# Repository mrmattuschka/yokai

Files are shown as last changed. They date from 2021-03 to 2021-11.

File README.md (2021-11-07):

# YŌKAI - An e-Paper navigation display for Komoot

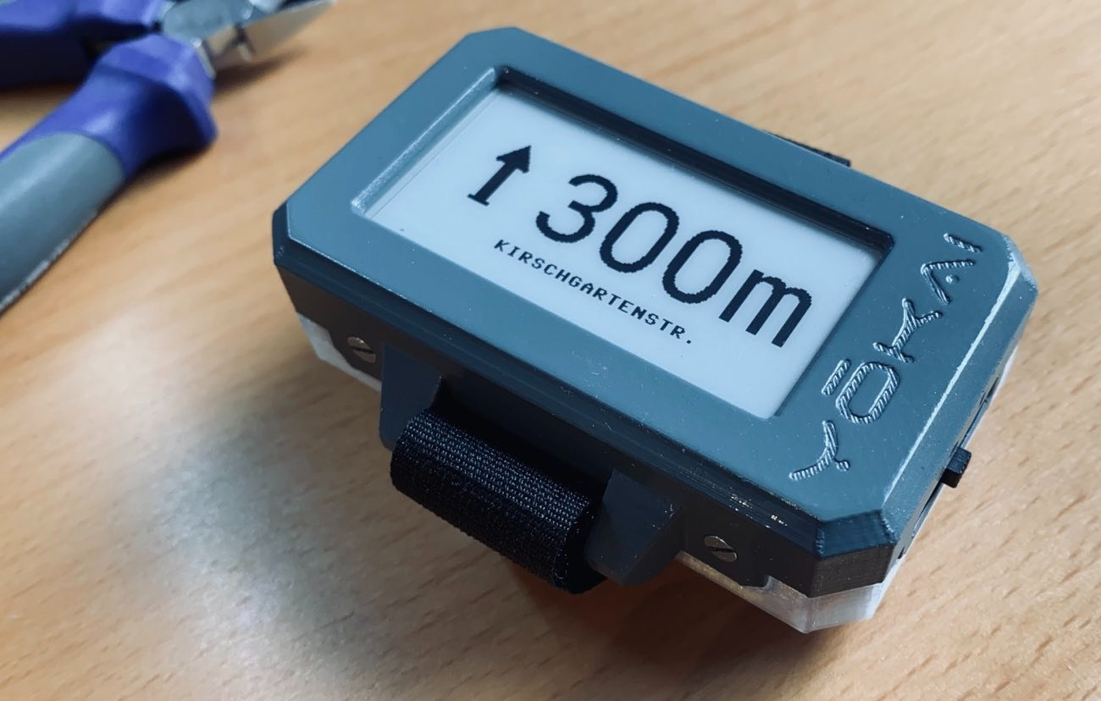
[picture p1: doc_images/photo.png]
YOKAI


Yokai is an open-source navigation instruction display based on an ESP32 microcontroller running MicroPython.
It hooks into [Komoot](https://apps.apple.com/app/komoot/id447374873)'s Bluetooth API running on a smartphone (currently only supporting iOS).
While Komoot is responsible for all the GPS and navigation magic, Yokai merely display the navigation instructions while your phone sits snugly in your pocket. Using a velcro strap, you can attach it to a bike handle or wear it on your wrist.
The e-Paper display ensures great visibility outdoors, and together with communication over Bluetooth Low Energy (BLE) the power consumption is minimal: your phone will run out of juice long before Yokai. And compared to your usual bike computer this thing is dirt cheap.

The name "Yōkai" stems from Japanese folklore, where it describes supernatural spirits and entities.

## How to build a Yōkai
**Please note:** The current model of Yokai runs on a LOLIN32 Lite connected to a e-Paper HAT originally designed for Raspberry Pis. Getting those two connected involves quite a bit of soldering, even more if you want to monitor battery voltage. However, I have since found out about the [LILYGO T5 v2.3](https://de.aliexpress.com/item/32869729970.html), which combines an ESP32 with the very same e-Paper display on the same PCB! Using this board will make building a Yokai a lot easier, and I am now working on porting Yokai to the T5. But if you feel like tinkering, here's how to build your very own Yokai:

Tools you will need:
- A 3D printer of your choice to print the case
- A soldering iron
- A set of tiny screwdrivers
- Crimping tools (or just some plyers) for JST plugs.
- Some wrenches that can handle the very small nuts used here. I ended up just printing some, check the [3D prints](./assembly/3d_prints/).

The parts required (as well as the 3D print files) can be found in the [BOM](./assembly/bom.md). I printed the case top and the ESP mounting bracket in eSUN PLA+, and the case bottom in translucent PETG for extra style points. Depending on your color choice you might want to fully print the parts in PETG to any dark-colored PLA getting soft when heated up by sunlight.

### Assembly
Not going to provide detailed assembly instructions because I'm now working on the T5 version, but have this exploded view:

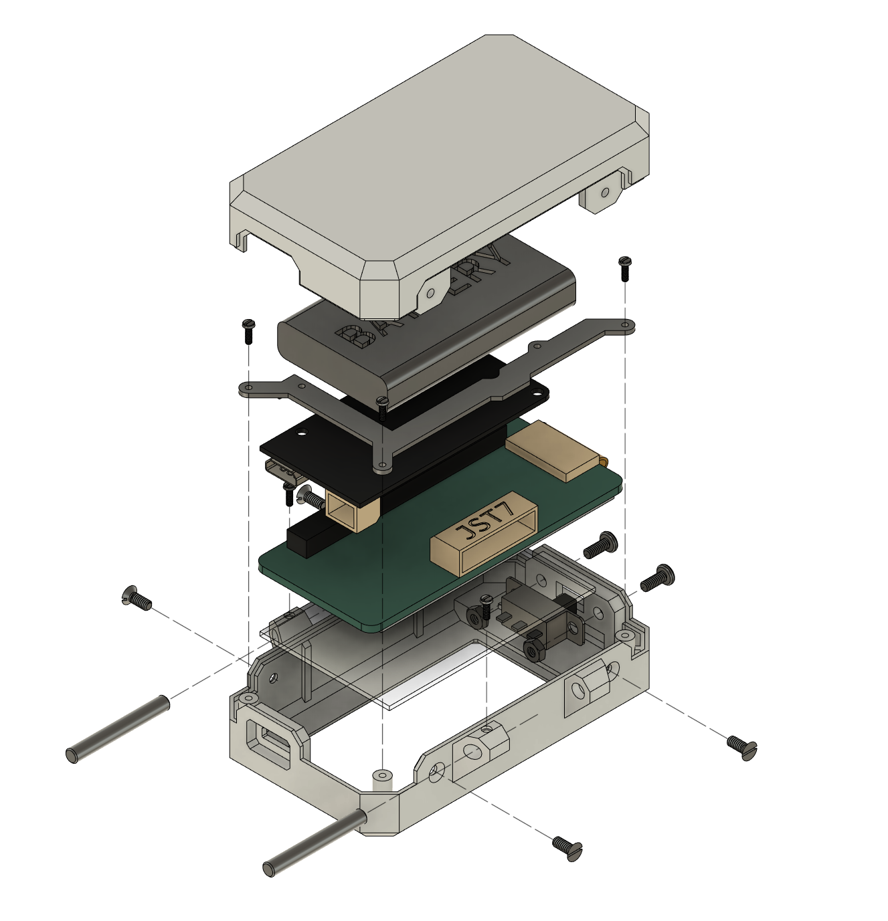
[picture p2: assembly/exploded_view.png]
Exploded view


Not pictured here: the LOLIN32 is mounted to its bracket using two of the M1.2 screws and nuts, as well as the 3D-printed washers. The polycarbonate screen is simply glued to the case top.

**TODO: add wiring instructions**

### Software setup

1. Install micropython on your LOLIN32: Go to the [micropython documentation](https://docs.micropython.org/en/latest/esp32/tutorial/intro.html#esp32-intro) and follow the instructions. Note that you need micropython >= 1.16.
2. Clone this repo if you haven't yet.
3. Using [ampy](https://github.com/scientifichackers/ampy), [rshell](https://github.com/dhylands/rshell) etc. copy the contents of the `src` directory onto the LOLIN32.

## How to use Yōkai

1. If you are interested in a Yokai, I assume you're already using Komoot. But if for some reason you haven't yet, install [Komoot](https://apps.apple.com/app/komoot/id447374873) from the app store.
2. Open Komoot, go to the profile section and open the settings menu (little cogwheel on the top).
3. Navigate to 'Bluetooth Connect' and connect to a new device. Pick any of the shown bike computers, doesn't really matter which. Make sure Bluetooth is enabled!
4. Turn on your Yokai. After a few seconds it should automatically detect your Phone and connect to it. Komoot will display a checkmark next to the chosen device.
5. Start a trip using Komoot & Yokai! Whenever going on another trip, just start the navigation on your Phone and turn on Yokai right after. Make sure that your phone is unlocked until Yokai has successfully connected, I haven't figured out yet how to deal with iOS's different BLE behaviour when the phone is locked.

## TODOs
- **ADD WIRING INSTRUCTIONS**
- **Switch to LILYGO T5** - This will eliminate almost all the soldering that is currently required!
- Android support - currently only iOS is supported
- Better user interface - better font for street names, cleaner direction arrows
- Make this work on a [Watchy](https://watchy.sqfmi.com/) (assuming I can actually get my hands on one)
- ...

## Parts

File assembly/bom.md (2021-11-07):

| Part | Qty. | Comments |  
| :--- | :--- | :--- |
| LOLIN32 Lite board v1.0.0 | 1 |  |
| Waveshare 2.13" e-Paper Display HAT | 1 |  |
| MakerFocus 3.7 V  1100 mAh rechargeable battery | 1 |  |
| JST 2 plug, 7-pin | 1 | Comes with e-Paper display, wires attached|
| JST 2 plug, 2-pin (+ crimp contacts) | 1 | To replace JST 1.25 plug on battery |
| Steel rods, 3 x 24mm | 2 |  |
| 100 kOhm resistors | 2 | Optional, to create a voltage divider for battery charge monitoring. |
| T 215 miniature slide switch | 1 |  |
| M2 screws, 5 mm, sunken head | 4 |  |
| M2 screws, 5 mm, round head + nuts | 2 | Come with e-Paper display |
| M1.3 screws, 4mm | 7 (+2 nuts) | [These](https://www.amazon.de/dp/B075SCV69H/ref=cm_sw_em_r_mt_dp_Y26N9AWJ7ZG0QT24DFXA?_encoding=UTF8&psc=1) aren't exactly M1.2 but work well|
| Polycarbonate screen 1 mm, UV resistant, cut to 52.5 x 33 mm | 1 |  |
| Case top (3D print) | 1 | [STL](./3d_prints/Case_Top.3mf) |
| Case bottom (3D print) | 1 | [STL](./3d_prints/Case_Bottom.3mf)  |
| Bracket to mount ESP (3D print) | 1 | [STL](./3d_prints/ESP_Bracket.3mf)  |
| Washers, 4 x 1.6 x 0.6 mm (3D print) | 1 | [STL](./3d_prints/4x1.6x0.6_washer.3mf) |
| Velcro strap | 1 | 20 cm for bike handles, 30 cm to strap to your wrist |

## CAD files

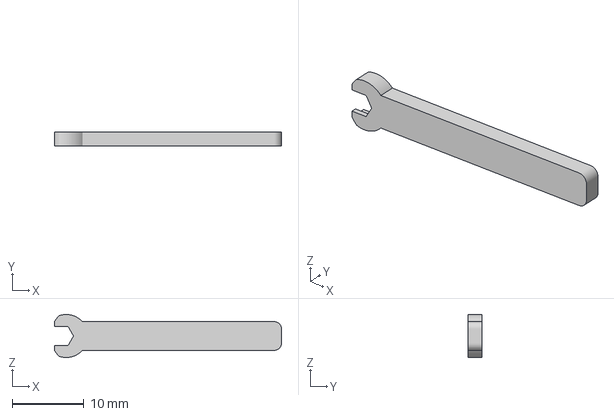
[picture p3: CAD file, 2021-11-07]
assembly/3d_prints/microwrench_4mm.3mf
31.7 x 2.00 x 6.00 mm

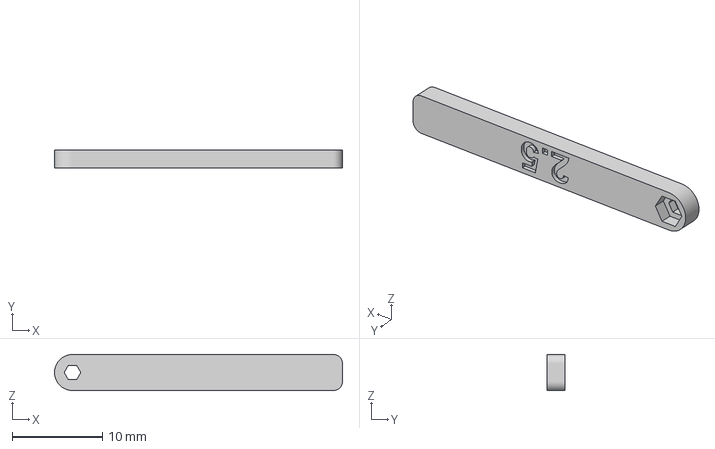
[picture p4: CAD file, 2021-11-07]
assembly/3d_prints/microwrench_2.5mm.3mf
32.0 x 2.00 x 4.00 mm

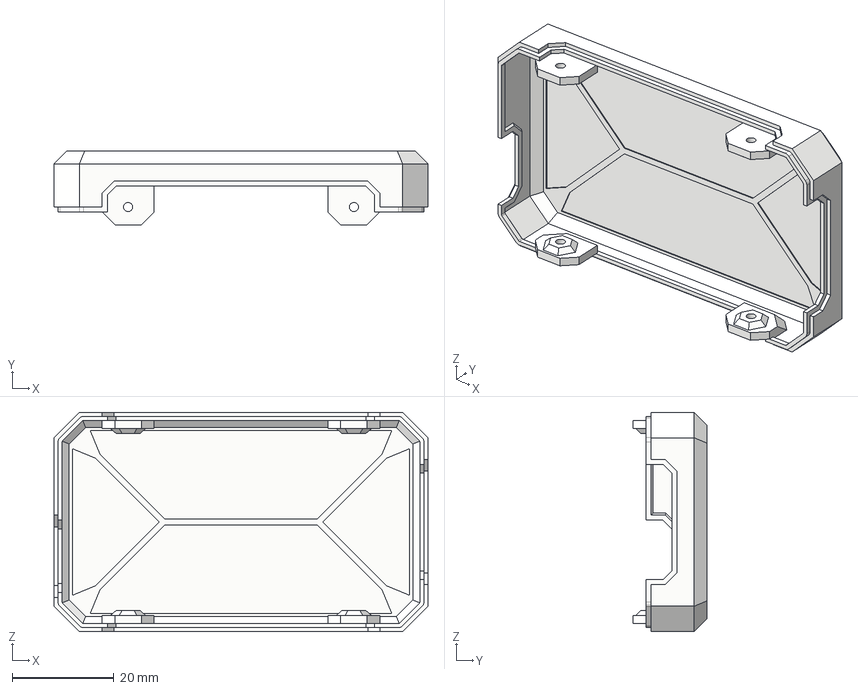
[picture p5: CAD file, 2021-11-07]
assembly/3d_prints/Case_Bottom.step
73.7 x 14.5 x 43.2 mm

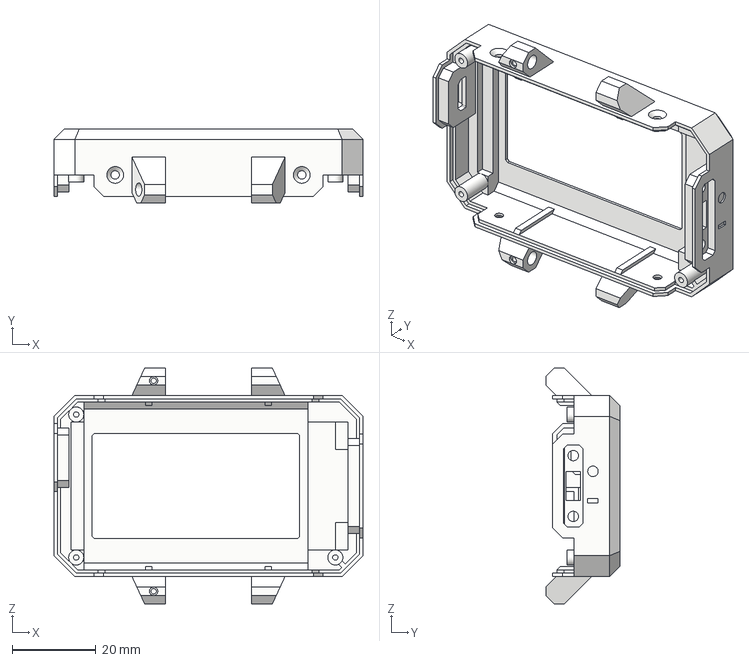
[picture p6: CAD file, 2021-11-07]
assembly/3d_prints/Case_Top.step
73.7 x 17.8 x 56.2 mm

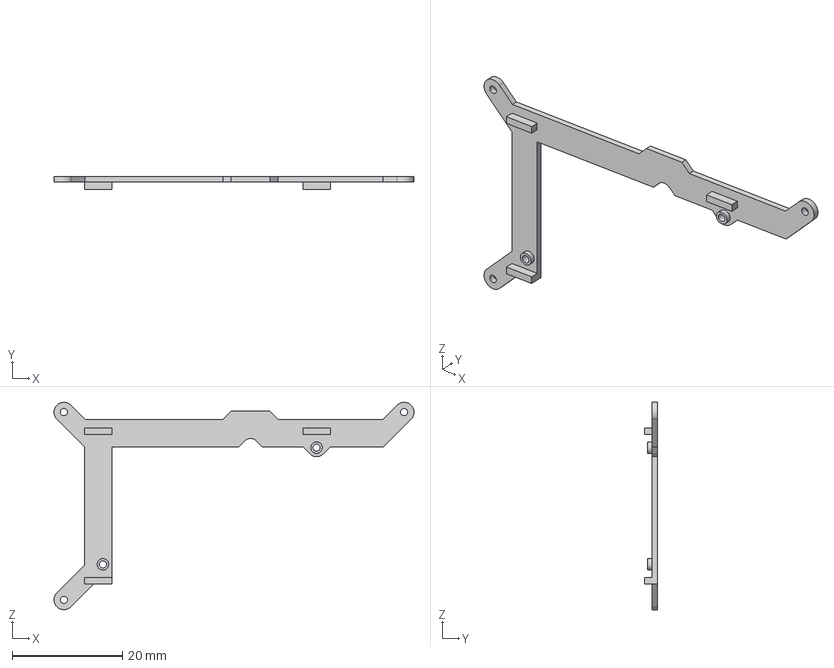
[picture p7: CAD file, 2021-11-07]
assembly/3d_prints/ESP_Bracket.step
65.4 x 2.40 x 37.7 mm

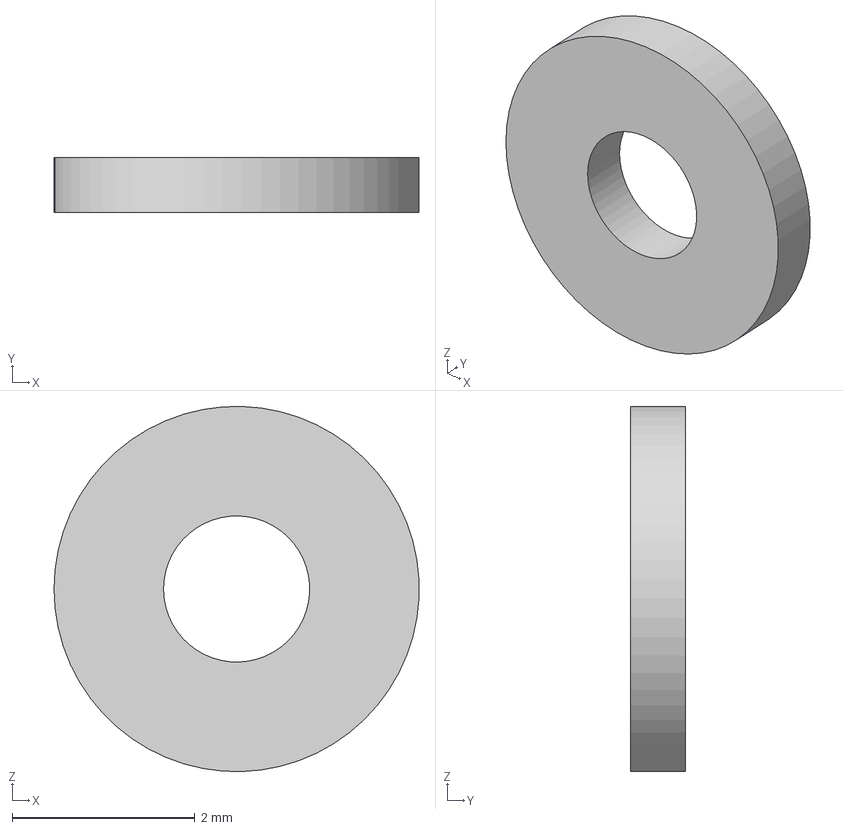
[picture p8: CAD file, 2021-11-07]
assembly/3d_prints/4x1.6x0.6_washer.step
4.00 x 0.6 x 4.00 mm

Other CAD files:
assembly/3d_prints/4x1.6x0.6_washer.3mf
assembly/3d_prints/Case_Bottom.3mf
assembly/3d_prints/Case_Top.3mf
assembly/3d_prints/ESP_Bracket.3mf

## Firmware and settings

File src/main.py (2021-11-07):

__version__ = "0.1.1"
__yokai_model__ = "1"

import sync_ubt
import struct
import time
import epd2in13_V2
from utils import Logger, DisplayRenderer
from machine import Pin, ADC, deepsleep

class KomootError(Exception):
    pass

komoot_svc_rev = b'lC\xb3\x1d\x17\x0f\xb2\xa2\xa8O/\xd9(\xe1\xc1q' # Stuff to locate komoot dev in adv mode
komoot_svc_uuid = "71C1E128-D92F-4FA8-A2B2-0F171DB3436C"
komoot_chr_uuid = "503DD605-9BCB-4F6E-B235-270A57483026"

global komoot_dev
komoot_addr = None
komoot_dev = None
nav_interval = 2

global last_nav
last_nav = None

# failure counter
global failures
failures = 0


log = Logger(max_len=12)
log.log("YOKAI model {m} firmware v{v}".format(m = __yokai_model__, v = __version__))

# Display properties
w = 250
h = 128

DPR = DisplayRenderer(w, h, mode="blank", logger=log)

# Initialize E-paper display
log.log("Initializing EPD...")
EPD = epd2in13_V2.EPD()
EPD.init(EPD.FULL_UPDATE)

# Set conditional EPD update as logger callback
def logger_display_callback(Logger):
    if DPR.mode == "term":
        render = DPR.render()
        EPD.display_cycle(render, cycle=False)
        del render

DPR.mode = "term"
render = DPR.render()
EPD.display_cycle(render, cycle=True) # Cycle once
del render

log.callback = logger_display_callback

# get SyncBLE interface
log.log("Initializing BLE interface...")
sbt = sync_ubt.SyncBLE(debug_logger=log.log)

# Voltage monitor
bat_monitor = ADC(Pin(34))
bat_monitor.atten(ADC.ATTN_11DB)

def get_bat_voltage():
    U = (bat_monitor.read()/4095)*3.6*2
    return U

def setup_komoot_dev(timeout=10, interval_ms=1000):
    """
    Detect and connect to a nearby BLE peripheral running Komoot.

    Parameters
    ----------
    timeout: int, optional
        time to wait in seconds for successful connection before failing (default 10).
    interval_ms: int, optional
        scanning interval in milliseconds (default 1000)

    Returns
    ----------
    a sync_ubt.Peripheral instance referring to the connected device
    """

    start = time.time()
    while time.time() < (start + timeout):
        devs = sbt.scan(interval_ms)

        for dev in devs.values():
            # Identify whether device is running Komoot
            adv_data = sync_ubt.decode_adv_data(dev["adv_data"])
            if adv_data.get("07", None) != komoot_svc_rev:
                continue

            log.log("Found device running Komoot:", dev["addr_decoded"])
            komoot_dev = sbt.connect(dev["addr_type"], dev["addr_decoded"])

            if komoot_dev is None:
                raise KomootError("Unable to connect to Komoot device")
            else:
                # Get device name from generic access SVC
                devname = "Unknown device"

                generic_acc = komoot_dev.get_service(0x1800)
                if generic_acc:
                    devname_chr = generic_acc[0].get_characteristic(0x2A00)
                    if devname_chr:
                        devname = devname_chr[0].read().decode()
                        komoot_dev.name = devname

                log.log("Connected to device: '{}'".format(devname))

                # Find Komoot SVC & CHR, register notify
                komoot_svc = komoot_dev.get_service(komoot_svc_uuid)

                if not komoot_svc:
                    raise KomootError("No Komoot SVC found")
                else:
                    log.log("Found Komoot SVC, locating CHR...")
                    komoot_chr = komoot_svc[0].get_characteristic(komoot_chr_uuid)

                    if not komoot_chr:
                        raise KomootError("No Komoot CHR found")
                    else:
                        log.log("Found Komoot CHR, registering...")
                        komoot_chr[0].register_notify()
                        komoot_dev.komoot_chr = komoot_chr[0]
                        log.log("Setup complete. Happy hiking!")
                        return komoot_dev

    else:
        raise KomootError("No device running Komoot found")

def decode_nav_data(data):
    """
    Decode navigation instructions retrieved from the Komoot app.
    Documentation on navigation instructions can be found here: https://docs.google.com/document/d/1iYgV4lDKG8LdCuYwzTXpt3FLO_kaoJGGWzai8yehv6g
    """
    if data is None:
        return None, None, None, None
    else:
        try:
            nav_id, nav_dir, dist = struct.unpack("<IbI", data[0:9])
            street = data[9:].decode()
            return nav_id, nav_dir, dist, street
        except ValueError:
            return None, None, None, None

def nav_routine():
    global komoot_dev
    global last_nav
    global failures

    if komoot_dev is None:
        log.log("Searching for Komoot device...")
        DPR.mode = "blank"
        komoot_dev = setup_komoot_dev()
        DPR.mode = "term"
        log.callback(None)

    if not komoot_dev.connected: # Returns zero on failure/no connection
        log.log("Komoot device is not connected, reconnecting...")
        komoot_dev = None
        komoot_dev = setup_komoot_dev()

    if komoot_dev.connected:
        DPR.mode = "nav"

        bat_voltage = get_bat_voltage()
        DPR.bat_voltage = bat_voltage
        
        nav_data = komoot_dev.komoot_chr.read()
        nav_id, nav_dir, dist, street = decode_nav_data(nav_data)
        
        if nav_id is not None:
            log.log(nav_id, nav_dir, dist, street)
            DPR.nav_data = [nav_id, nav_dir, dist, street]
            render = DPR.render()

            if (dist > 200): 
                if (street != last_nav): # only do full refresh if we have more than 200m and new street
                    log.log("Cycling display...")
                    EPD.display_cycle(render, cycle=True)
                time.sleep(5)
            else:
                EPD.display_cycle(render, cycle=False)
            del render
            last_nav = street

        else:
            log.log("No nav data available.")
            DPR.nav_data = [None, 30, 0, "No nav data"]
            render = DPR.render()
            EPD.display_cycle(render, cycle=True)
            del render
            time.sleep(5)
    else:
        raise KomootError("Komoot device not connected")


while failures < 10:
    try:
        nav_routine()
    except Exception as e:
        DPR.mode = "term"
        log.log(e.__class__.__name__ + ':', str(e))
        failures += 1
        time.sleep(5)
    else:
        # If nav_routine succeeds, reset failure counter.
        failures = 0
else:
    DPR.mode = "term"
    log.log(">10 failures, going into deep sleep.\nCycle device to try again.")
    deepsleep()

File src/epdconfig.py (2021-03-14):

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

# import logging <- not present on ESP
import time
import sys
from machine import SPI, Pin
from micropython import const

RST_PIN = const(16)
DC_PIN = const(17)
CS_PIN = const(5)
BUSY_PIN = const(4)


class ESP32:

    def __init__(self):
        self.SPI = SPI(2, baudrate=1000000, sck=Pin(18), mosi=Pin(23))
        # Stating this seems to be important! make sure SPI gets initialized
        #SPI(2, baudrate=1000000)
        self.rst = Pin(RST_PIN)
        self.dc = Pin(DC_PIN)
        self.cs = Pin(CS_PIN)
        self.busy = Pin(BUSY_PIN)

        self.GPIO = {
            RST_PIN : self.rst,
            DC_PIN : self.dc,
            CS_PIN : self.cs,
            BUSY_PIN : self.busy
        }


    def digital_write(self, pin, value):
        self.GPIO[pin].value(value)

    def digital_read(self, pin):
        return self.GPIO[pin].value()

    def delay_ms(self, delaytime):
        time.sleep_ms(delaytime)

    def spi_writebyte(self, data):
        self.SPI.write(bytearray(data))

    def module_init(self):
        self.cs.init(self.cs.OUT, value=1)
        self.dc.init(self.dc.OUT, value=0)
        self.rst.init(self.rst.OUT, value=0)
        self.busy.init(self.busy.IN)
        return 0

    def module_exit(self):
        # logging.debug("spi end")
        self.SPI.deinit()

        # logging.debug("close 5V, Module enters 0 power consumption ...")
        self.rst.value(0)
        self.dc.value(0)


implementation = ESP32()

for func in [x for x in dir(implementation) if not x.startswith('_')]:
    setattr(sys.modules[__name__], func, getattr(implementation, func))


### END OF FILE ###

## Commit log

2021-09-12 Added voltage meter
2021-10-02 Fixed OOM issue when using micropython>=1.16
    [utils.py]
2021-10-02 Fixed display repeatedly fully refreshing at >200m
    [main.py]
2021-11-07 Added deepsleep on reaching error limit
    [main.py]
2021-11-07 Added BOM, 3d print STLs
    [4x1.6x0.6_washer.3mf, 4x1.6x0.6_washer.step, Case_Bottom.3mf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]
2021-11-07 Added assembly instructions
    [4x1.6x0.6_washer.3mf, 4x1.6x0.6_washer.step, Case_Bottom.3mf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]
